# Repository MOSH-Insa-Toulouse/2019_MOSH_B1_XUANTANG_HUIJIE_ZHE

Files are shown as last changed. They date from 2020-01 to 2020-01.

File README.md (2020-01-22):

# 2019_MOSH_B1_XUANTANG_HUIJIE_ZHE_MOHAN
This project aims to develop a dangerous gas detecting system, whose buzzer will alarm as soon as the gas index is higher than the warning line. The system includes programming the software based on Arduino, sending the data of gas sensor to TTN platform via LoRa, using Node-Red to display our data on a graphical interface and finally designing the PCB board by Kicad. 
 
 Documents in attachment
- Arduino Software files 
- Kicad files 
- Node-Red dashboard

## Arduino
Components:
- An Arduino uno board
- A Lora chip RN2483A
- A Grove Gas Sensor
- A buzzer
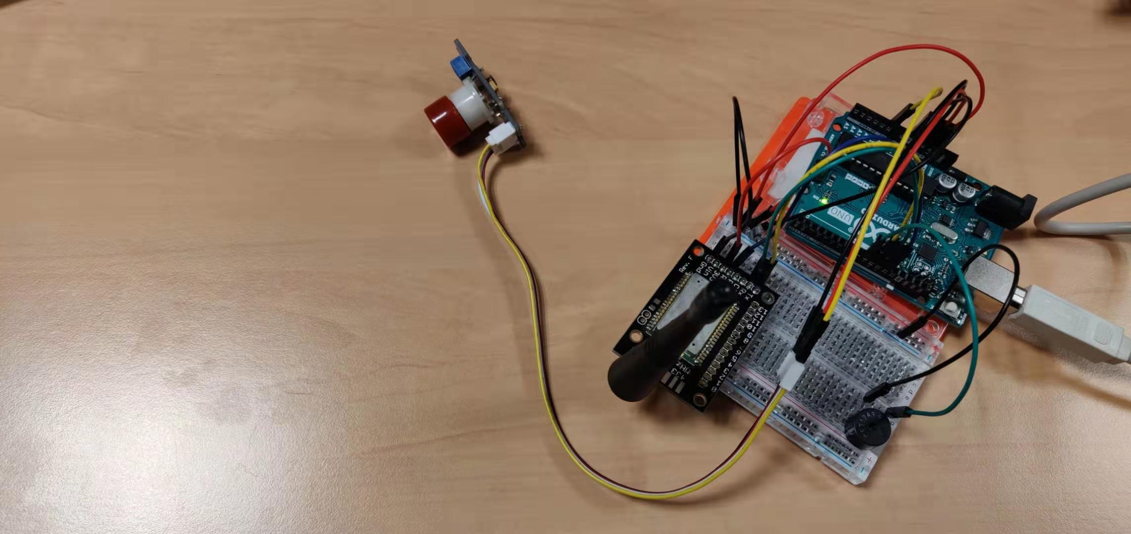
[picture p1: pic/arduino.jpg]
avatar Figure 1: Arduino


With Arduino, we achieve to make a detecting system that when the gas index is higher than our standard, the buzzer will alarm. We used interruption of arduino to do this. The code is in the folder.
After the soldering of the LoRa chip RN2483A, we succeed in communicating with the TTN platform, here is the screenshot of TTN:

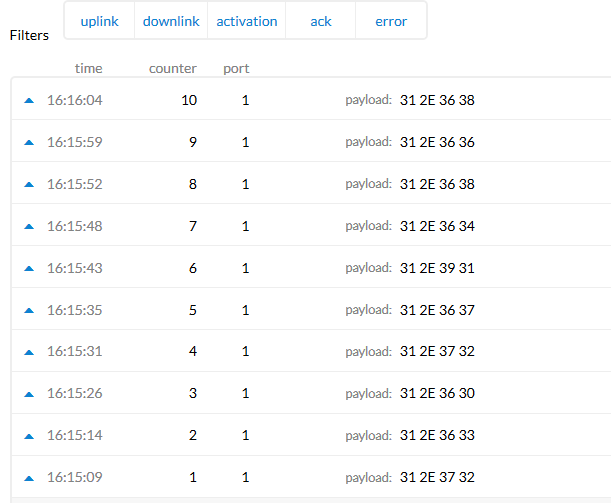
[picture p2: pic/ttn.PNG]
avatar Figure 2: ttn data


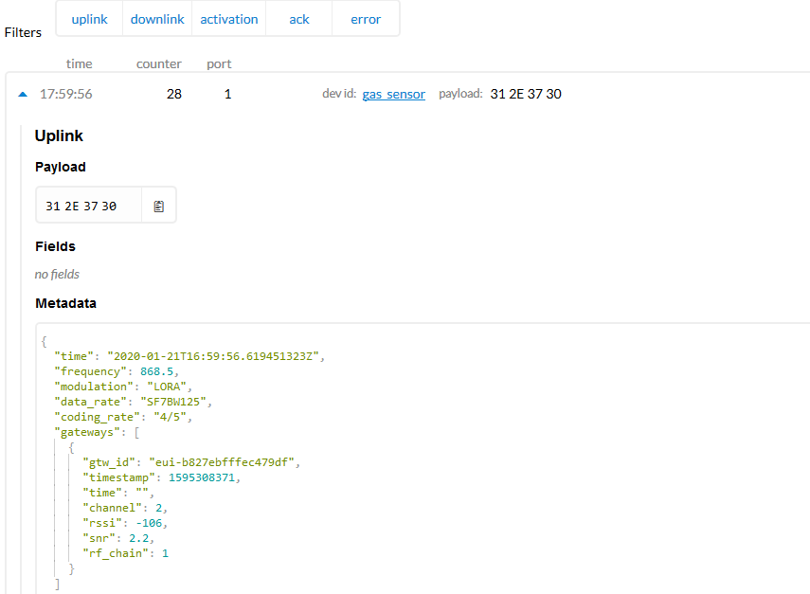
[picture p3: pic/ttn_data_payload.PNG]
avatar Figure 3: ttn data payload


Energy Consumption
To reduce the energy consumption, we decide to decrease the frequency of transmitting by sending data only when the gas index is higher than a seuil, otherwise, the LoRa system is in sleep mode. The energy consumption befor is 1.5W, and now the energy consumption reduced to 1.1W.

Node-Red
Finally, we did a dashboard by Node-Red, retrieving the data from TTN platform.
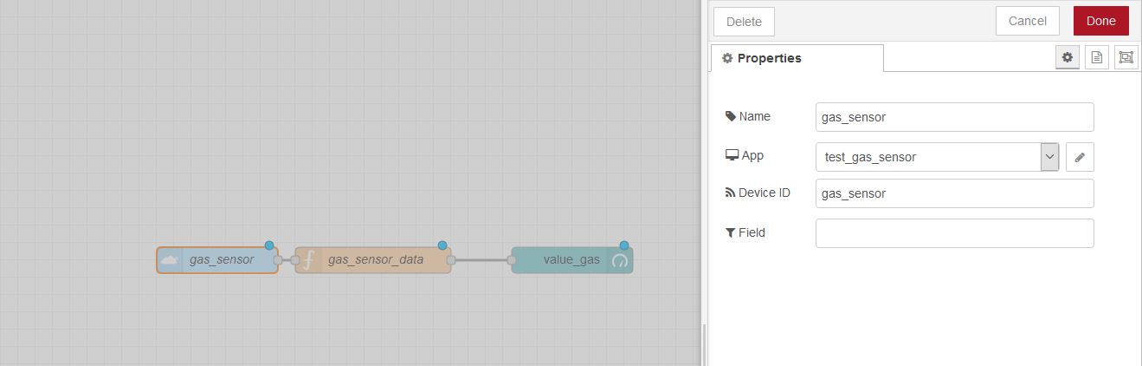
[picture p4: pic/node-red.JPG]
avatar Figure 4: flow of node-red


## kicad

In order to establish the best circuit between the LoRa module and the gas sensor introduced in the MOSH section above, we have drawn the following circuit diagram, which includes our components: a LoRa Module (RN2483) as transceiver, a Gas sensor, an amplifier (LTC1050) and two connector.

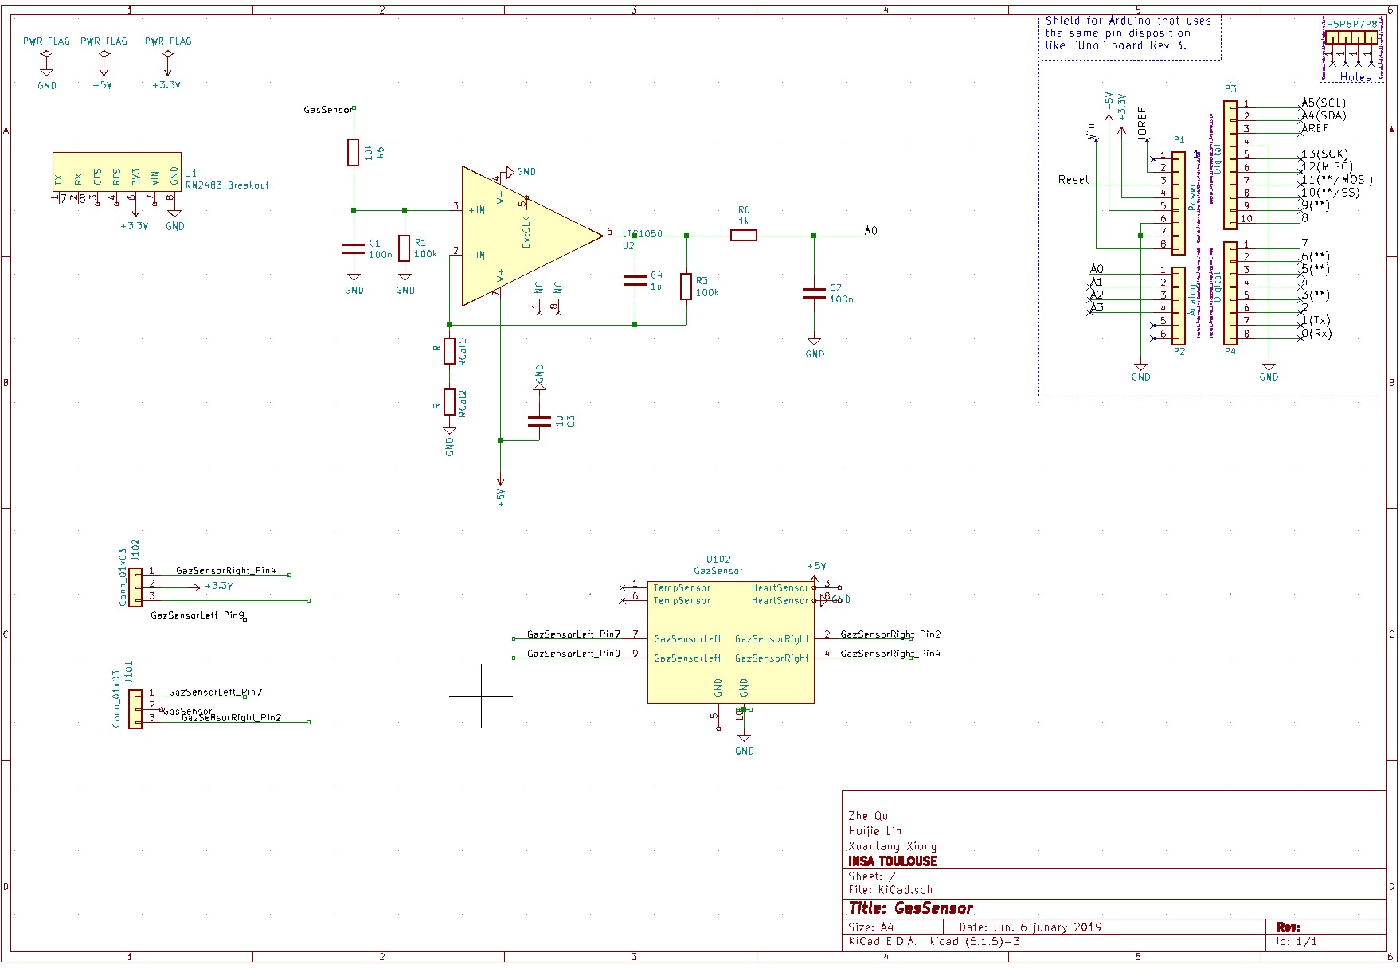
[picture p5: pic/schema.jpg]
avatar Figure 5: Diagram of the shield's electrical circuit


After the electrical diagram is completed, the different components must be packaged and integrated on a board. This is a complicated process, we have to consider the placement of components and the problem of circuit connection. The principle is to make the connection as simple as possible, without interleaving, and to ensure the safety of the circuit based on the correct circuit connection. Our results are as follows:

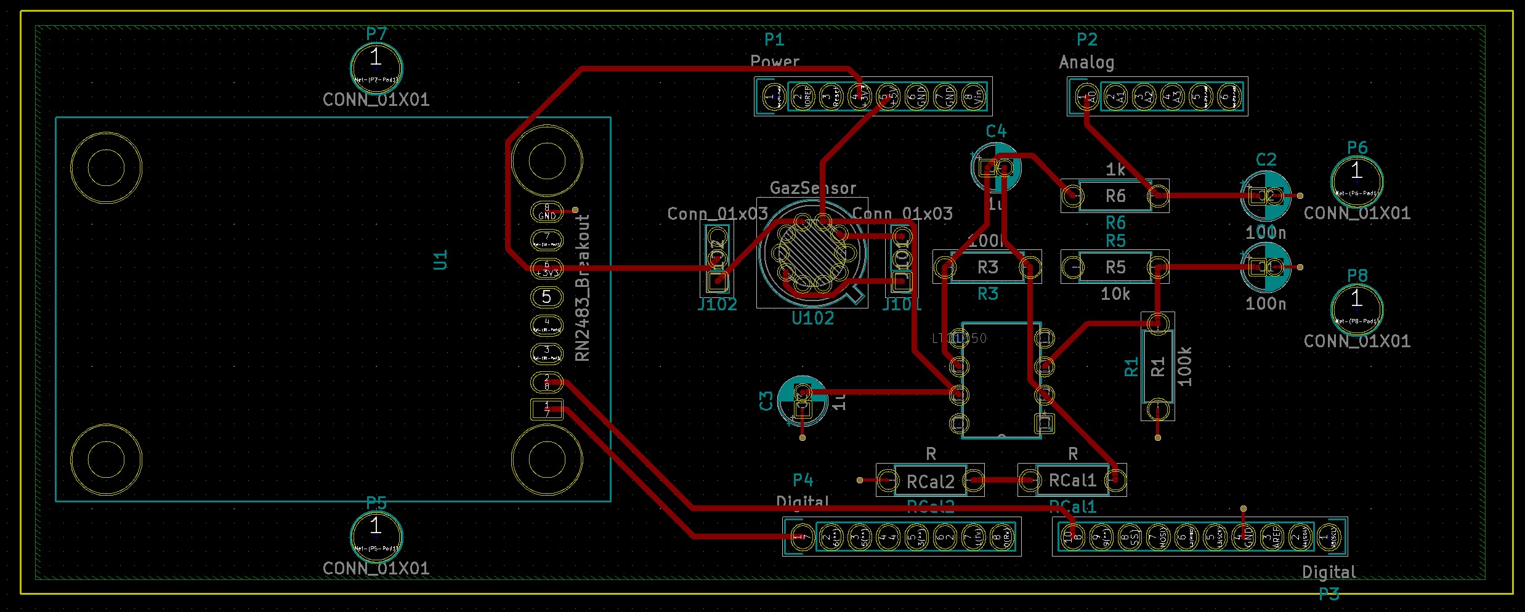
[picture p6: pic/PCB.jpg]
avatar Figure 6: Printed circuit board 1

We have not only adjusted the layout of the components, but also considered the thickness and spacing of the connected copper wires, because copper wires that are too thin or too close will cause safety issues.

We used two layers of circuits, the lower layer was connected to ground, the voltage was zero. All the arrangements of wire are on the upper layer of the pcb board. If we need to connect to the ground, we will make a hole.
All the arrangements of wire are on the upper layer of the pcb board. If we need to connect to the ground, we will make a hole. The advantage of this method is that the upper circuit can be more concise.
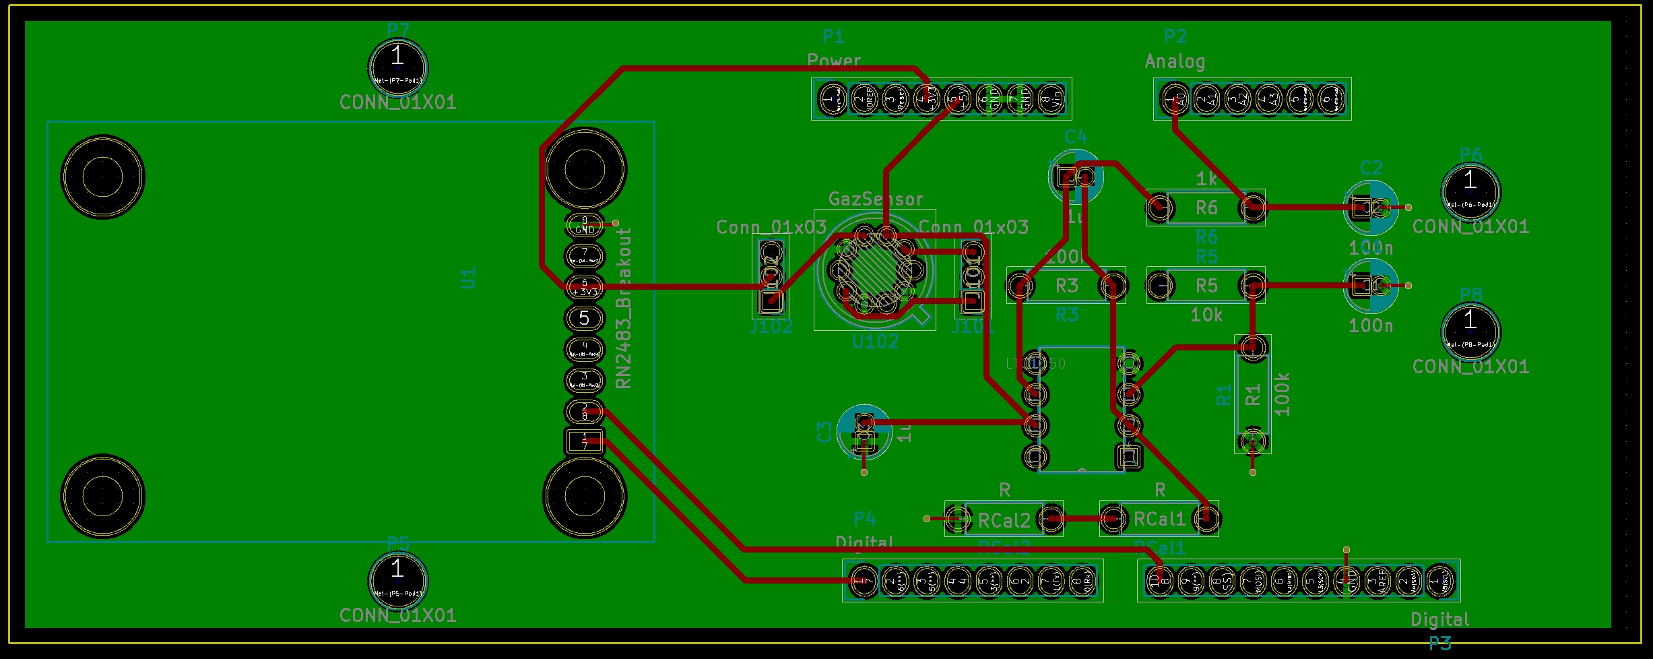
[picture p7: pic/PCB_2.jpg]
avatar Figure 7: Printed circuit board 2


Here is the final 3d model of our results:
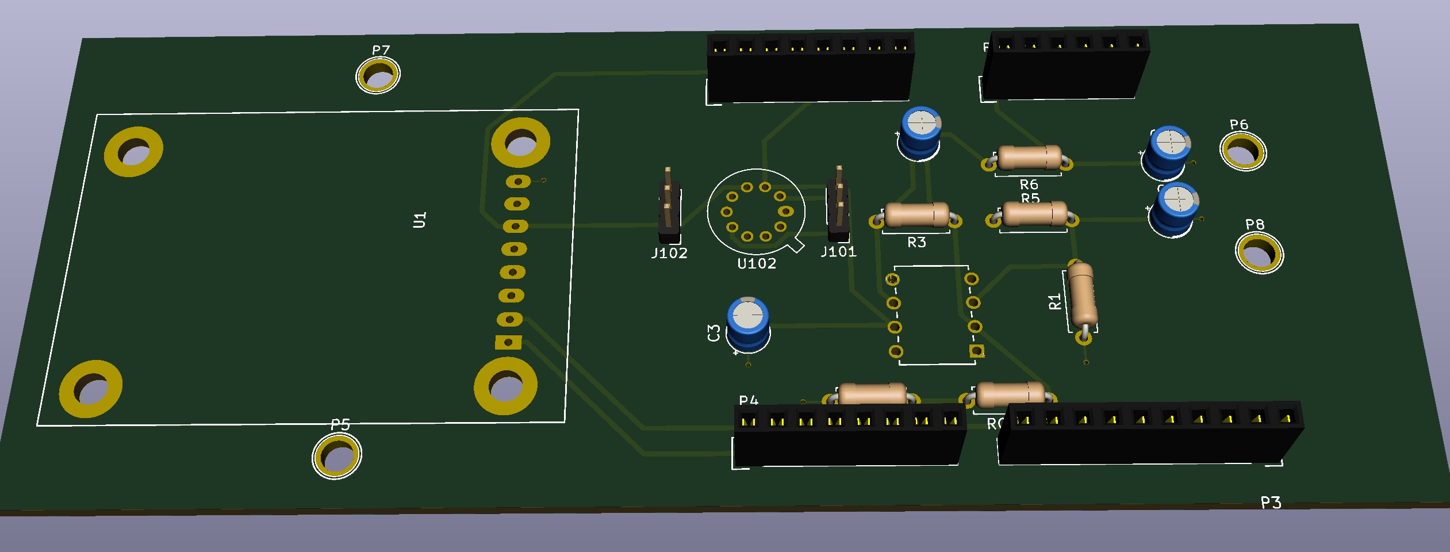
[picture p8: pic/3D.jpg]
avatar Figure 8: 3D Model


## Part LTSpice

The stage is composed of several filters and an operational amplifier. We used LTSpice to simulate the analog circuit.
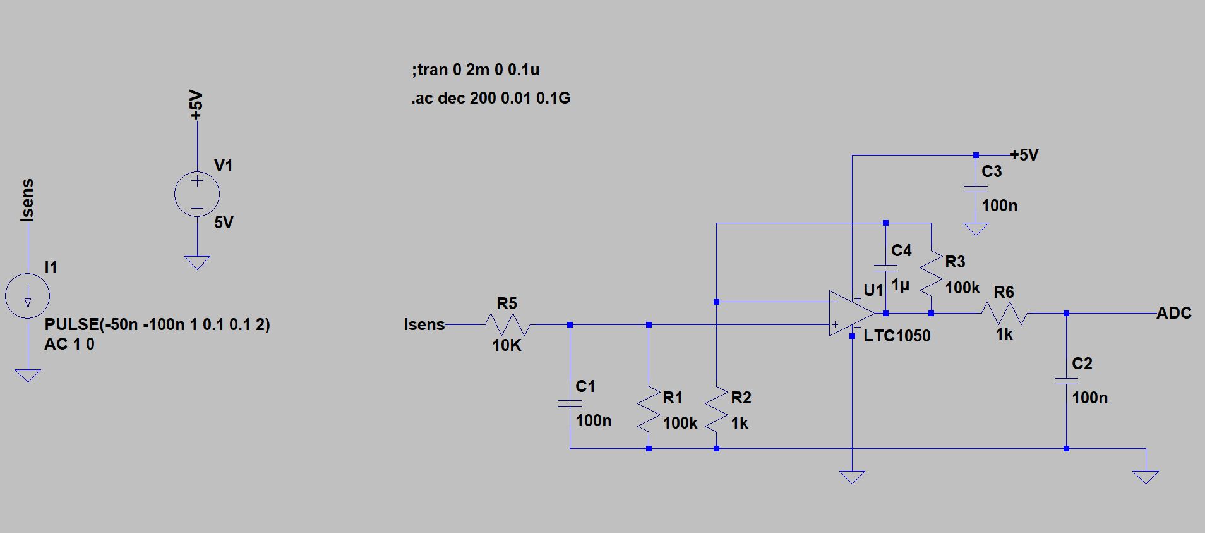
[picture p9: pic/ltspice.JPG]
avatar Figure 9: Ltspice


#### Question 1: check the operation in nominal conditions
Normally, the circuit amplify with a gain equals 100.
#### Question 2:  is the impact of the LTC1050C amplifier offset acceptable ?
The offset of input is 0.5mv, with our gain of 100, the offset of output 50mv which make 1 digit error in the 12 bits ADC.
#### Question 3:  is the impact of the amplifier input current acceptable ?
With the data sheet of ltc1050, we got the input noise current is 1.8fA/sqrt(HZ). So with a signal of 1KHz, we have an erreur 5.6E-14 << 1E-9 

#### Question 4:  what is the cutoff frequency of each low-pass filter stage?
stage 1: 15.9Hz
stage 2: 1.59Hz
stage 3: 1.59KHz
#### Question 5 : What is the global attenuation of a 50 Hz current noise ?
The global attenuation equals 40 dB of 50Hz current noise.

#### Question 6 : What is the global attenuation of a current noise occurring at the aliasing limit frequency (in the case of Arduino Uno ADC) ?
For a 16MHz Arduino, the ADC clock is set to 16MHz/128=125KHz. Each conversion takes 13 ADC clocks so 125KHz/13 = 9615Hz. At this frequency, we have an attenuation of 115 dB.

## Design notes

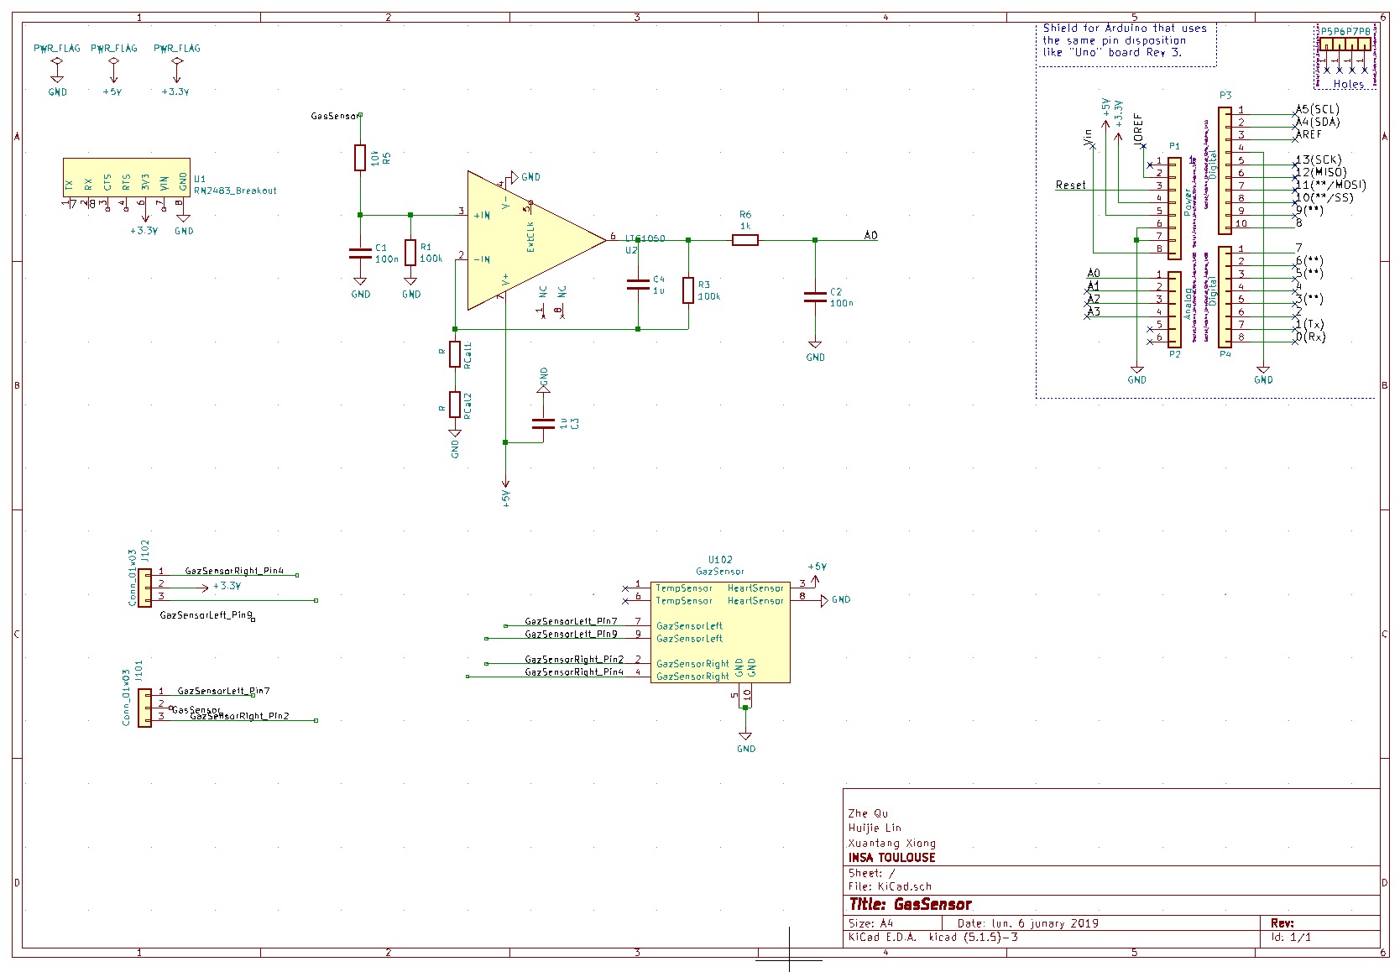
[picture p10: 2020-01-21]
pic/circuit_diagram.jpg

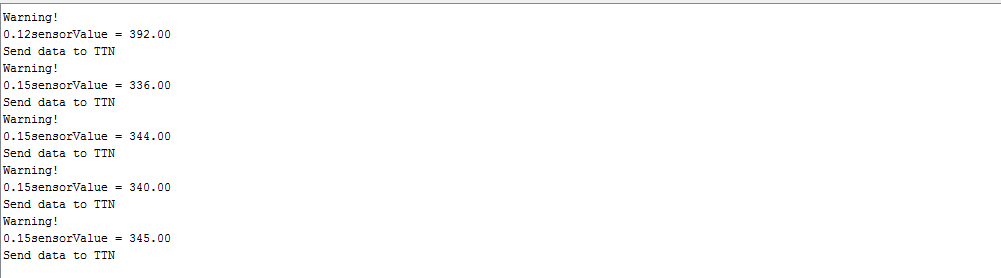
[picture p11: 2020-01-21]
pic/Serial_port.PNG

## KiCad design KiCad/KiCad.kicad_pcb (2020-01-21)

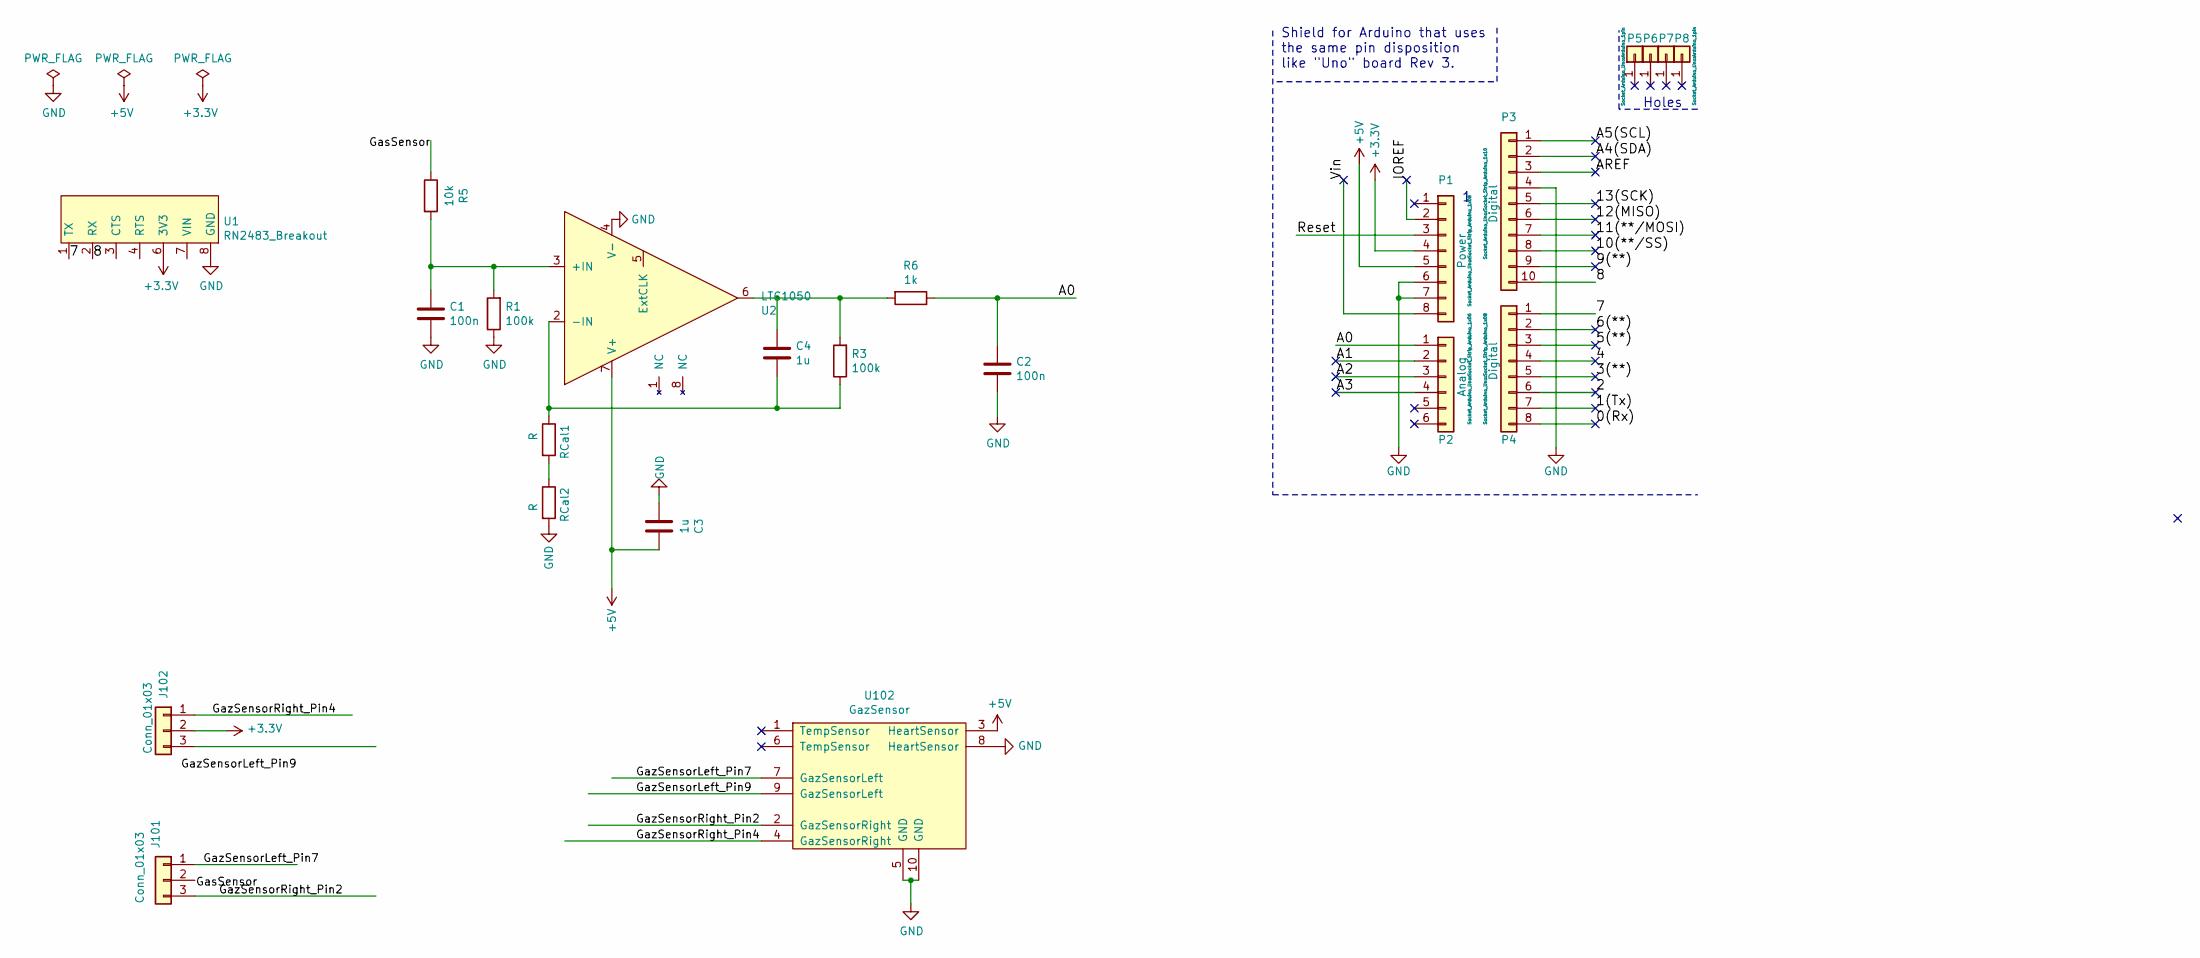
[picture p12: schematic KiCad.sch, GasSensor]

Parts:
C1, C2: 100n; CP_Radial_D4.0mm_P1.50mm
C3, C4: 1u; CP_Radial_D4.0mm_P1.50mm
J101, J102: Conn_01x03; PinHeader_1x03_P2.00mm_Vertical
P1: Power; Socket_Strip_Arduino_1x08
P2: Analog; Socket_Strip_Arduino_1x06
P3: Digital; Socket_Strip_Arduino_1x10
P4: Digital; Socket_Strip_Arduino_1x08
P5, P6, P7, P8: CONN_01X01; Arduino_1pin
R1, R3: 100k; R_Axial_DIN0207_L6.3mm_D2.5mm_P7.62mm_Horizontal
R5: 10k; R_Axial_DIN0207_L6.3mm_D2.5mm_P7.62mm_Horizontal
R6: 1k; R_Axial_DIN0207_L6.3mm_D2.5mm_P7.62mm_Horizontal
RCal1, RCal2: R; R_Axial_DIN0207_L6.3mm_D2.5mm_P7.62mm_Horizontal
U1: RN2483_Breakout
U2: LTC1050
U102: GazSensor; TO-5-10_Window

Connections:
+3V3: J102.2, P1.4, U1.6 (3V3)
+5V: C3.2, P1.5, U2.7 (V+), U102.3 (HeartSensor)
/0(Rx): P4.8
/1(Tx): P4.7
/2: P4.6
/3(**): P4.5
/4: P4.4
/5(**): P4.3
/6(**): P4.2
/7: P4.1, U1.1 (TX)
/8: P3.10, U1.2 (RX)
/9(**): P3.9
/10(**/SS): P3.8
/11(**/MOSI): P3.7
/12(MISO): P3.6
/13(SCK): P3.5
/A0: C2.1, P2.1, R6.1
/A1: P2.2
/A2: P2.3
/A3: P2.4
/A4(SDA): P3.2
/A5(SCL): P3.1
/AREF: P3.3
/GasSensor: R5.1
/GazSensorLeft_Pin7: J101.1, U102.7 (GazSensorLeft)
/GazSensorLeft_Pin9: U102.9 (GazSensorLeft)
/GazSensorRight_Pin2: J101.3, U102.2 (GazSensorRight)
/GazSensorRight_Pin4: J102.1, U102.4 (GazSensorRight)
/IOREF: P1.2
/Reset: P1.3
/Vin: P1.8
GND: C1.2, C2.2, C3.1, P1.6, P1.7, P3.4, R1.1, RCal2.2, U1.8 (GND), U2.4 (V-), U102.5 (GND), U102.8 (HeartSensor), U102.10 (GND)
unnamed: C1.1, R1.2, R5.2, U2.3 (+IN)
unnamed: C4.1, R3.2, R6.2, U2.6
unnamed: C4.2, R3.1, RCal1.1, U2.2 (-IN)
unnamed: RCal1.2, RCal2.1

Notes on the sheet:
Holes
Shield for Arduino that uses the same pin disposition like "Uno" board Rev 3.

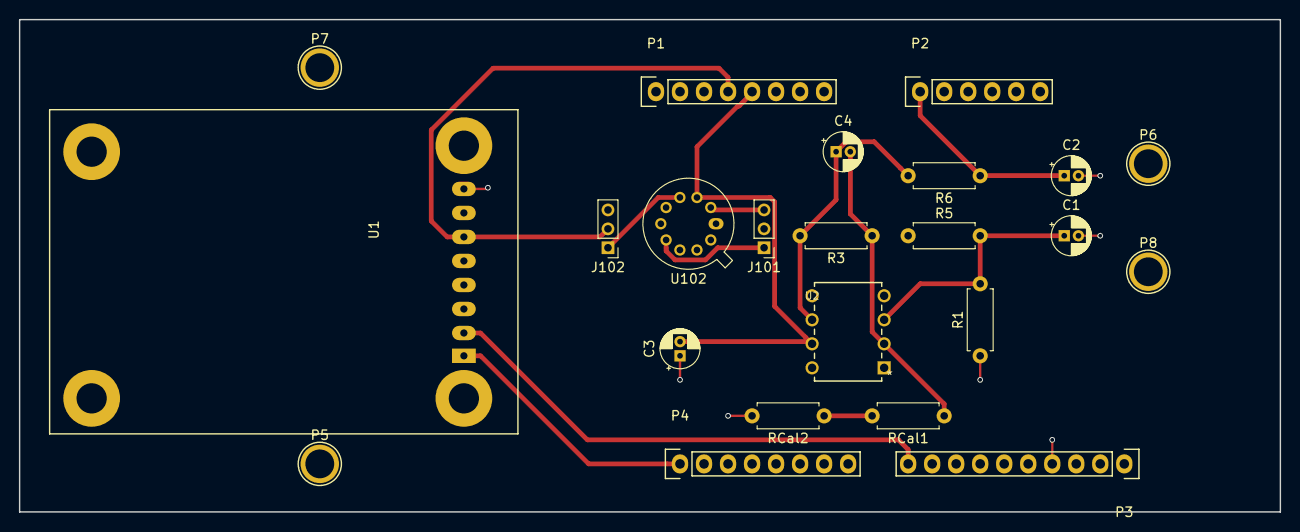
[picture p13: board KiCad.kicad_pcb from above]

Board: 2 copper layers, 133.3 x 52.1 mm, 23 parts (0 on the bottom side), 13 nets.

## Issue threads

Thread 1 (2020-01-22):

PCB routing

ArnauldDev, 2020-01-22:
Lors du routage d'un circuit électronique, vous devez router les pistes sur la couche B.Cu, face du dessous en verte par rapport aux composants.

When routing an electronic circuit, you must route the tracks on layer B.Cu, face down from green in relation to the components.

Arnauld

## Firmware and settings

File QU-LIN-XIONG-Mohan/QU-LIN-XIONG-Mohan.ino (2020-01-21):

/*
 * Author: Zhe QU, Huijie LIN, Xuantang XIONG, Mohan
 * Date: 2016-02-07
 * Previous filename: TTN-Mapper-TTNEnschede-V1
 */

 //la consommation 1.5W = 0.3A*5.03V
 //la consommation résuite = 1.1w = 0.22*5v
#include <rn2xx3.h>
#include <SoftwareSerial.h>

SoftwareSerial mySerial(10, 11); // TX, RX

//create an instance of the rn2xx3 library,
//giving the software serial as port to use
rn2xx3 myLora(mySerial);

// the setup routine runs once when you press reset:
void setup()
{
  //output LED pin
  pinMode(13, OUTPUT);
  led_on();
  pinMode(2, OUTPUT);
  pinMode(9, OUTPUT);
  pinMode(3, INPUT);
  // Open serial communications and wait for port to open:
  Serial.begin(57600); //serial port to computer
  mySerial.begin(9600); //serial port to radio
  Serial.println("Startup");

  initialize_radio();

  //transmit a startup message
  myLora.tx("TTN Mapper on TTN Enschede node");

  led_off();
  delay(2000);
  attachInterrupt(0, gestionINT0, RISING);
}

void initialize_radio()
{
  //reset rn2483
  pinMode(12, OUTPUT);
  digitalWrite(12, LOW);
  delay(500);
  digitalWrite(12, HIGH);

  delay(100); //wait for the RN2xx3's startup message
  mySerial.flush();

  //Autobaud the rn2483 module to 9600. The default would otherwise be 57600.
  myLora.autobaud();

  //check communication with radio
  String hweui = myLora.hweui();
  while(hweui.length() != 16)
  {
    Serial.println("Communication with RN2xx3 unsuccessful. Power cycle the board.");
    Serial.println(hweui);
    delay(10000);
    hweui = myLora.hweui();
  }

  //print out the HWEUI so that we can register it via ttnctl
  Serial.println("When using OTAA, register this DevEUI: ");
  Serial.println(myLora.hweui());
  Serial.println("RN2xx3 firmware version:");
  Serial.println(myLora.sysver());

  //configure your keys and join the network
  Serial.println("Trying to join TTN");
  bool join_result = false;


  /*
   * ABP: initABP(String addr, String AppSKey, String NwkSKey);
   * Paste the example code from the TTN console here:
   */
  const char *devAddr = "260110AF";
  const char *nwkSKey = "AAC5129D9BF1ADC1189D3A56228AD870";
  const char *appSKey = "ECABFD6C270D637CB9E26EC93FF9CBE3";

  join_result = myLora.initABP(devAddr, appSKey, nwkSKey);

  /*
   * OTAA: initOTAA(String AppEUI, String AppKey);
   * If you are using OTAA, paste the example code from the TTN console here:
   */
 /* const char *appEui = "70B3D57ED0025B12";
  const char *appKey = "EDDFF9E19CE4420D93384AC0DF829530";
  const char *devEui = "0004A30B00E96FE4";
  join_result = myLora.initOTAA(appEui, appKey, devEui);*/


  while(!join_result)
  {
    Serial.println("Unable to join. Are your keys correct, and do you have TTN coverage?");
    delay(60000); //delay a minute before retry
    join_result = myLora.initABP(devAddr, appSKey, nwkSKey);
  }
  Serial.println("Successfully joined TTN");
  }

  float sensor_volt;
  float sensorValue;
  float RS_gas;
  float ratio;
  float previous_sensorValue = 0;
  float R0 = 13.3;
// the loop routine runs over and over again forever:
void loop()
{
    sensorValue = analogRead(0);
    sensor_volt = sensorValue/1024*5.0;
    RS_gas = (5.0-sensor_volt)/sensor_volt;
    ratio = RS_gas/R0;
    Serial.print(ratio);
    Serial.print("sensorValue = ");
    Serial.print(sensorValue);
    Serial.print("\n");
    led_off();
    String gas = String(sensor_volt);
    if(abs(sensorValue-previous_sensorValue)>2){
      Serial.println("Send data to TTN");
      myLora.tx(gas);
      led_on();  
    }
    previous_sensorValue = sensorValue;
    if(ratio<5){
      digitalWrite(2,HIGH);
    }
    
    delay(2000);
}

void gestionINT0(){
  Serial.println("Warning!");
  for(int i=0;i<1000;i++){
    digitalWrite(9,HIGH);
    delay(1);
    digitalWrite(9,LOW);
  }
}


void led_on()
{
  digitalWrite(13, 1);
}

void led_off()
{
  digitalWrite(13, 0);
}
